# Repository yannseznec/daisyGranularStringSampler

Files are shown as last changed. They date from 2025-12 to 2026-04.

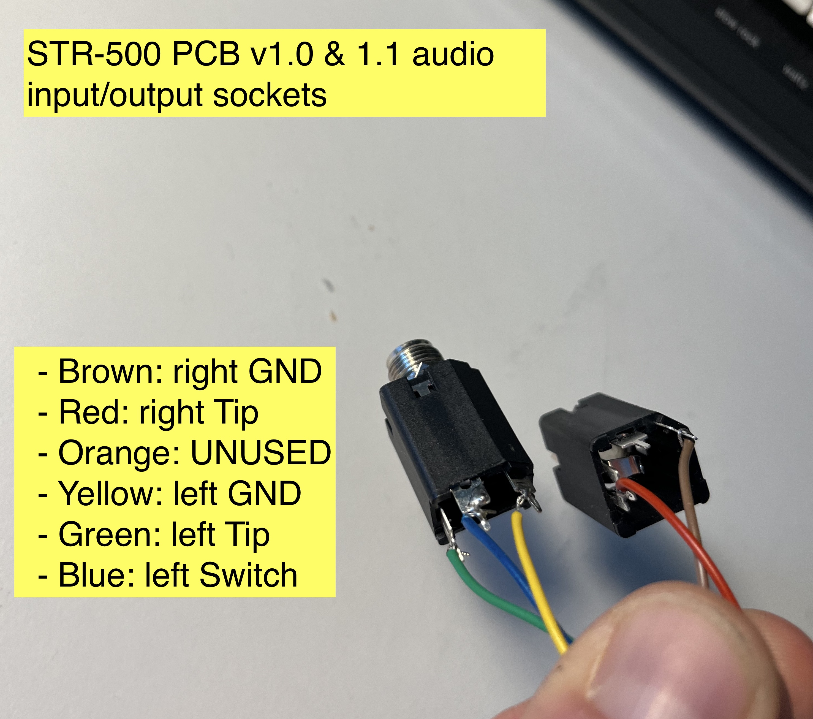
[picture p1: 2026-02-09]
build_notes_etc/picture_audio_sockets.jpg

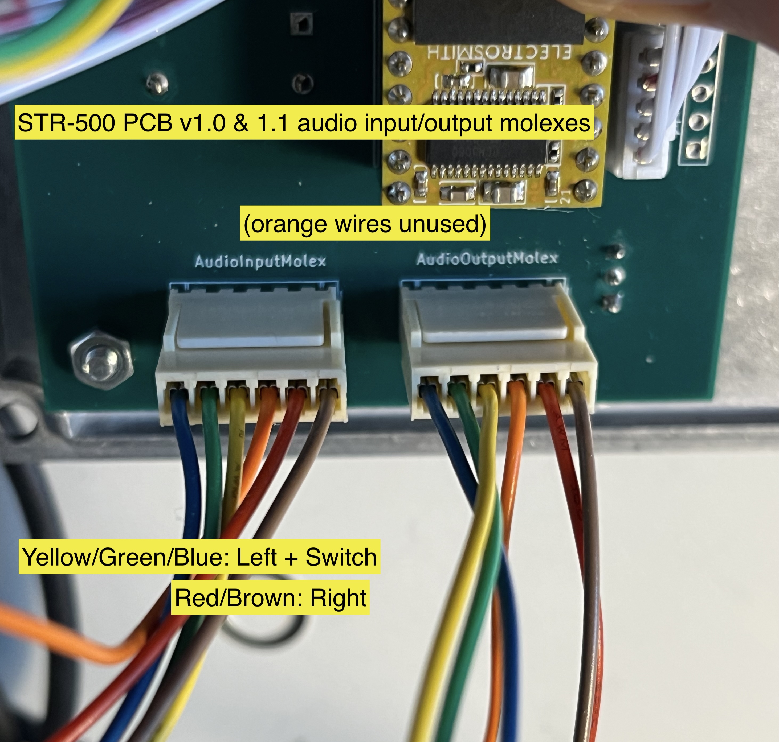
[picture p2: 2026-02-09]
build_notes_etc/picture_audio_molex.jpg

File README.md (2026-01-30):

## STR-500

This is all of the code and build info for the STR-500 gestural granular synthesizer. 

It is a granular synthesizer built for the Daisy Seed which uses a salvaged Gametrak string controller to playback a recorded sample. 

To-do: 
- develop this Readme
- add an actual to-do list to this Readme

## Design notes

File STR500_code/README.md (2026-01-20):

# Granular sampler for Daisy (STR-500)
This is a granular sampling system that runs on a Daisy Seed microcontroller.

Written in Pure Data. The easiest way to get it running on a Seed is to use PlugData for compiling. I use the "Big + SDRAM" SRAM setting in the compiler to allow for the relatively long sampling time. I set the blocksize to 10 for performance and noise reasons. 

This granular patch is essentially the same as the ys.granular system also available here on my github: https://github.com/yannseznec/ys.granular
The main difference is that this version does not use the [clone] object, which is not supported by the Heavy compiler required by the Daisy Seed. There are probably a few other similar changes that I can't remember right now.

This patch is particularly designed for use with a Gametrak string controller, resulting in a gestural sampling machine that I call the STR-500. More details on that coming at some point, you can see videos of it on my instagram if you like: https://www.instagram.com/p/DPdloWzjOOb/

There is a JSON file included for getting the interface elements (buttons, switches, Gametrak) connected to the Seed correctly. At some point I'll make a more detailed guide for how to get that to work. I've also included a KiCAD project for the PCB that I'm working on. This probably isn't the "final" version but it is working. I'll make a list of the components at some point.

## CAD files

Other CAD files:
STR500_v1.1_build/STR500_1-1_drill_drawings/STR500+Drawing+lid.dwg
STR500_v1.1_build/STR500_DXF_from_PCB/Side_gametrak_drill.dxf
STR500_v1.1_build/STR500_1-1_drill_drawings/STR500+Drawing+sockets.dwg
STR500_v1.1_build/STR500_DXF_from_PCB/str500v1.1_holes.dxf
STR500_v1.1_build/STR500_1-1_drill_drawings/STR500+Drawing+gametrak.dwg
STR500_v1.1_build/STR500_DXF_from_PCB/Side_sockets_drill.dxf
STR500_v1.1_build/STR500_1-1_drill_drawings/STR500+Drawing+gametrak.f3z

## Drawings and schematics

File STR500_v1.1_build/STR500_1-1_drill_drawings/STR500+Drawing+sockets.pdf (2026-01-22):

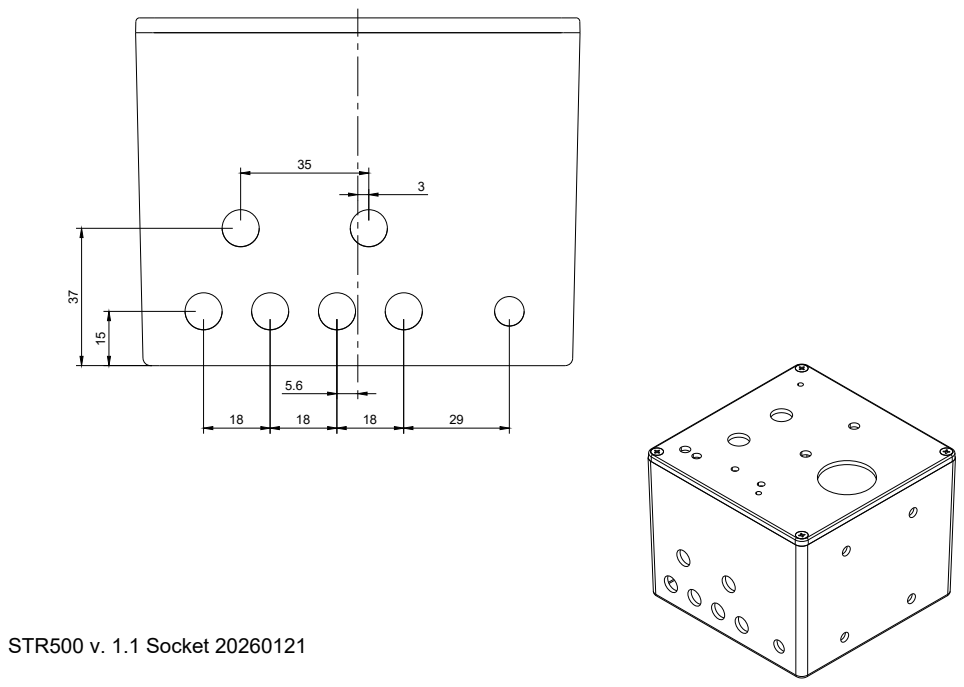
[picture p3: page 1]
STR500 v. 1.1 Socket 20260121

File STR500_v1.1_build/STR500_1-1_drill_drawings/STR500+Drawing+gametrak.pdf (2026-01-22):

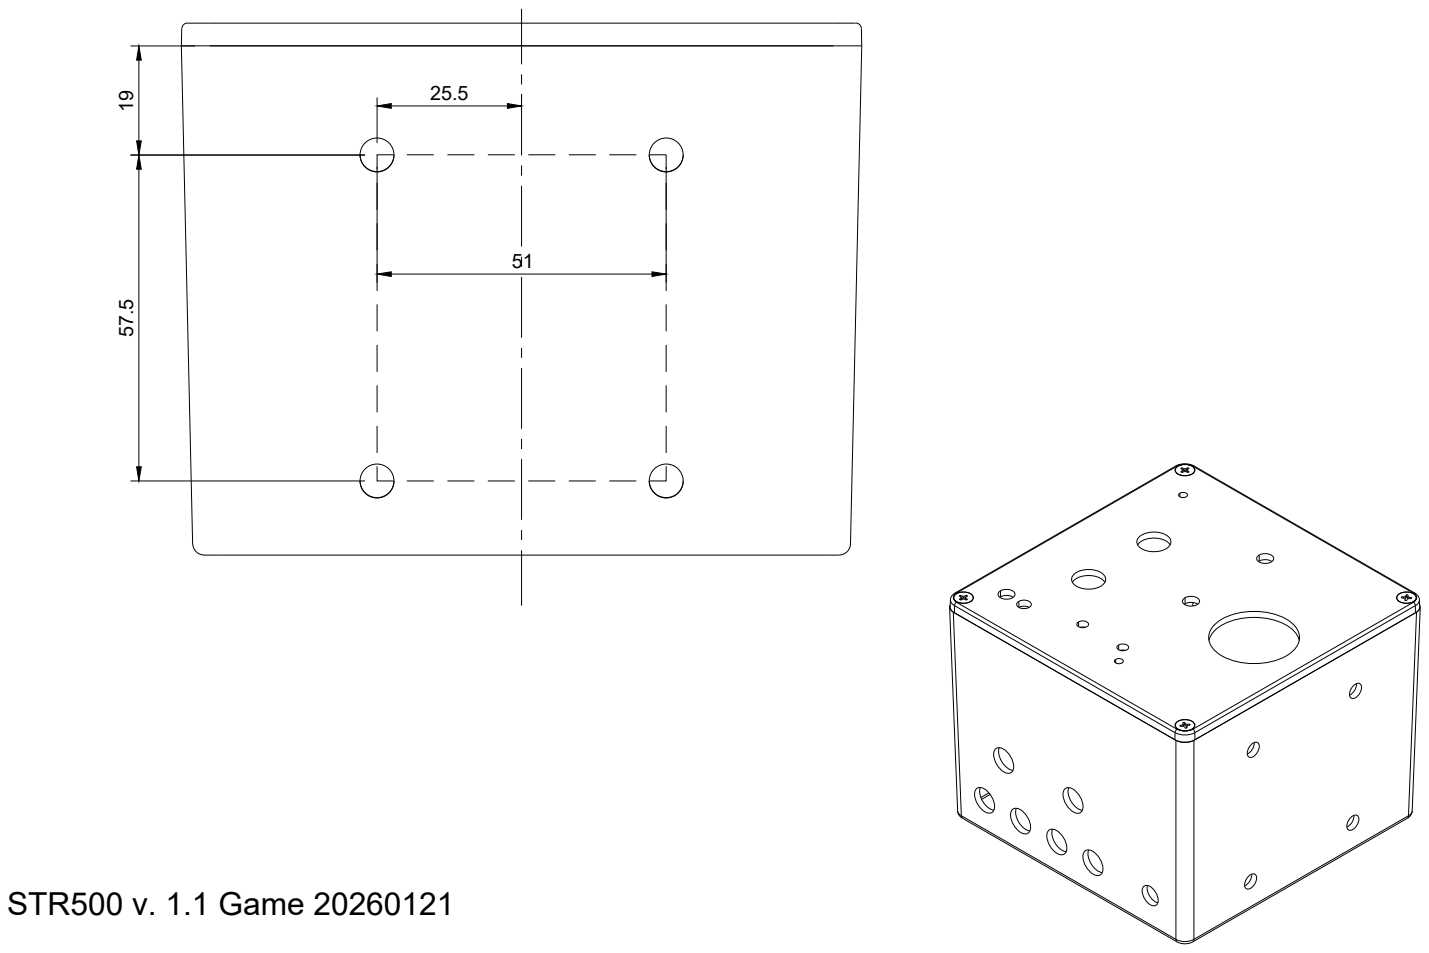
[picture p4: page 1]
STR500 v. 1.1 Game 20260121

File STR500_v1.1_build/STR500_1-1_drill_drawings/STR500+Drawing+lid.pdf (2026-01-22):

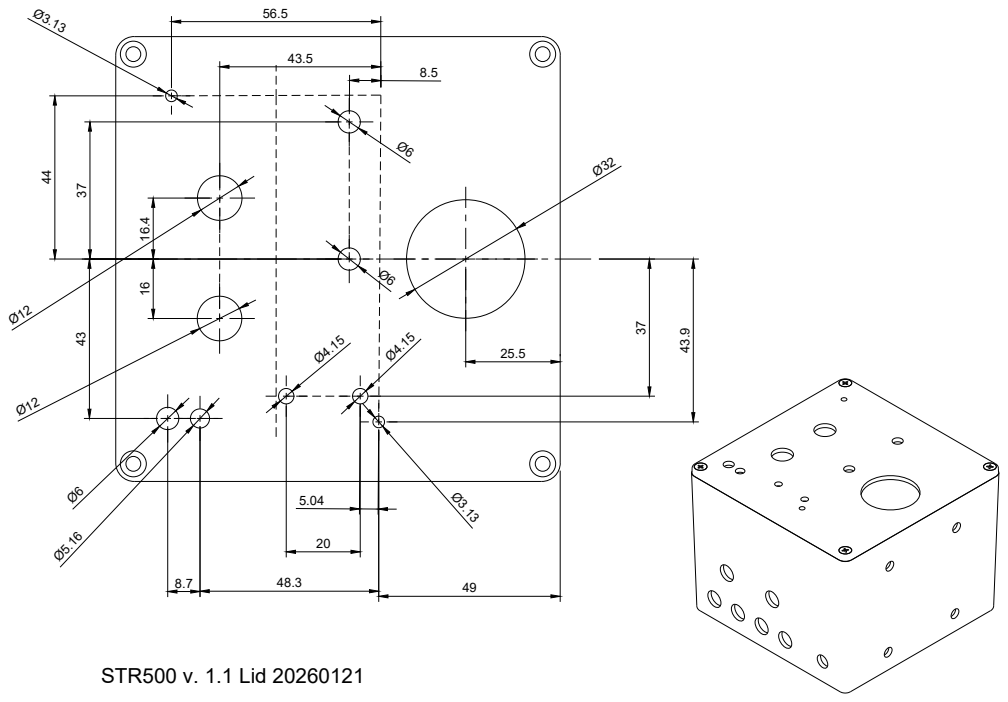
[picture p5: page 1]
STR500 v. 1.1 Lid 20260121

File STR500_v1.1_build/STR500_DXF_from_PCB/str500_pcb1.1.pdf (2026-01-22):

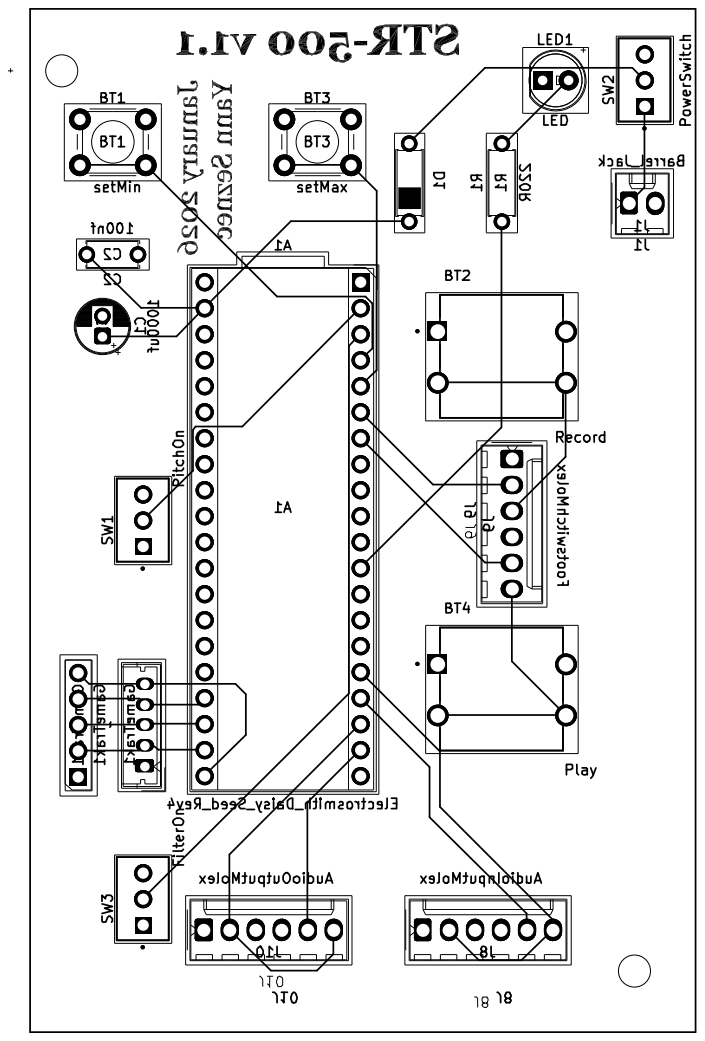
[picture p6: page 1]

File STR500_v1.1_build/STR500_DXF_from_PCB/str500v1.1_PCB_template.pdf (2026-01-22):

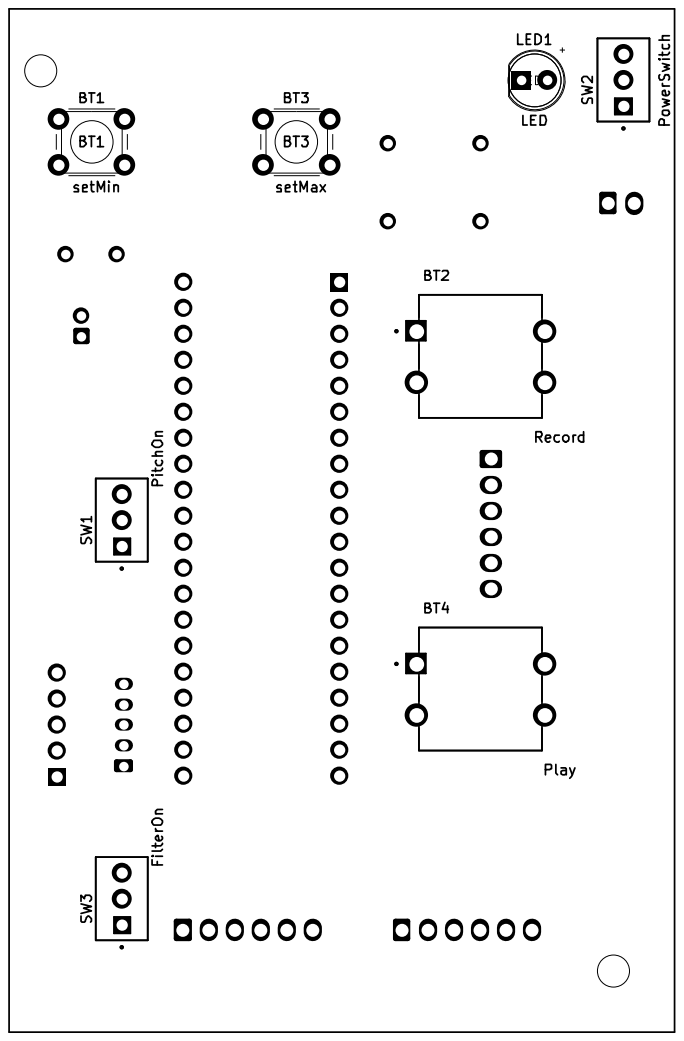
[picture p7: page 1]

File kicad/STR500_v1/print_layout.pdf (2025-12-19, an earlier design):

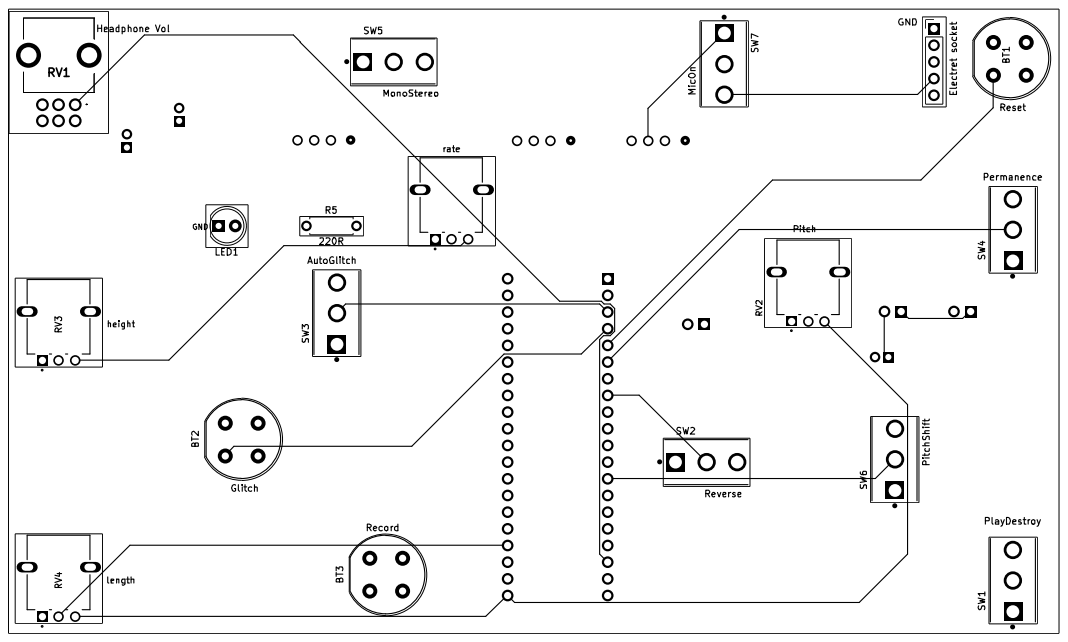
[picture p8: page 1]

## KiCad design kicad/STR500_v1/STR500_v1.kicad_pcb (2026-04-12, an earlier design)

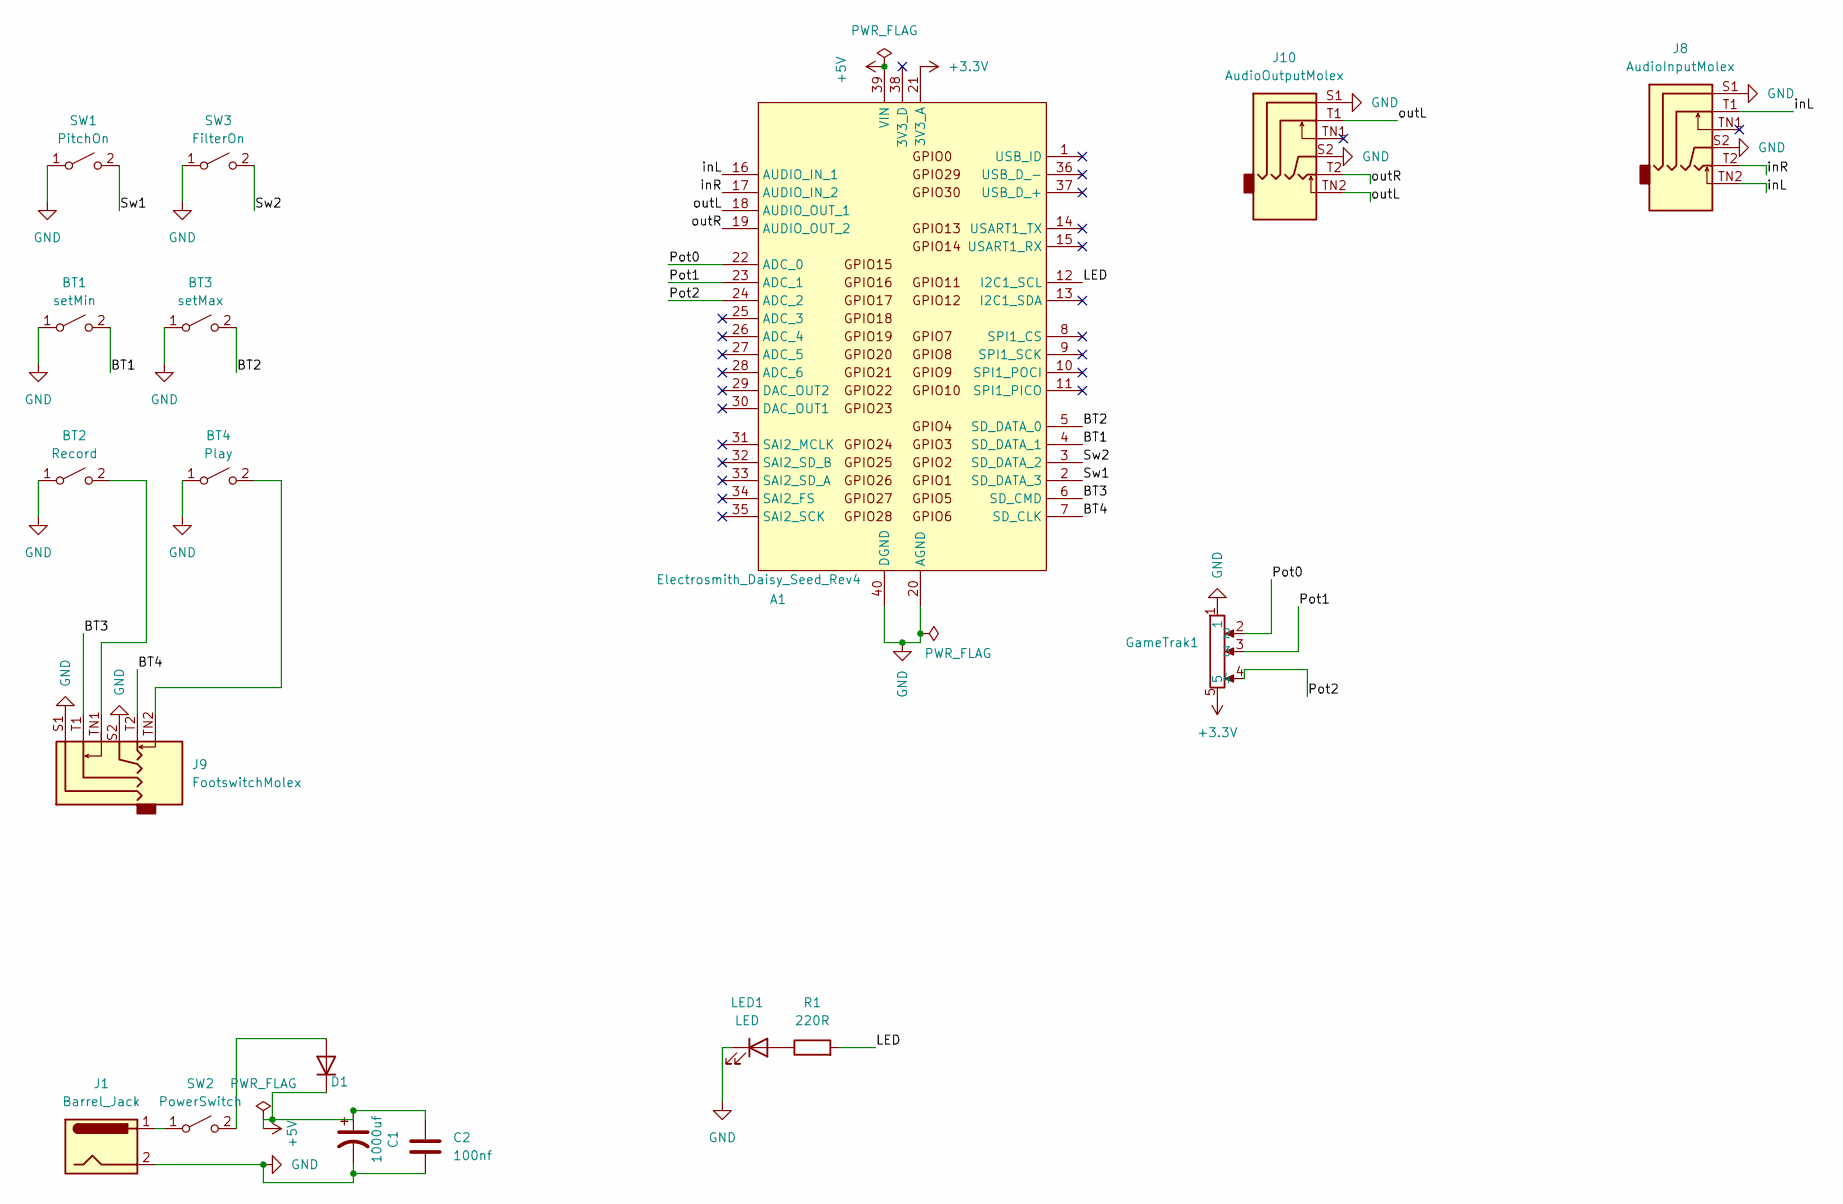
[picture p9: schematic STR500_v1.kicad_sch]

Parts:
A1: Electrosmith_Daisy_Seed_Rev4; Electrosmith_Daisy_Seed
BT1: setMin; SW_PUSH_6mm
BT2: Record; SW_TS13-1212-73-BK-160-D
BT3: setMax; SW_PUSH_6mm
BT4: Play; SW_TS13-1212-73-BK-160-D
C1: 1000uf; CP_Radial_D5.0mm_P2.00mm
C2: 100nf; C_Disc_D5.0mm_W2.5mm_P5.00mm
D1: D; R_Axial_DIN0207_L6.3mm_D2.5mm_P7.62mm_Horizontal
GameTrak1: Molex_Micro-Latch_53253-0570_1x05_P2.00mm_Vertical
J1: Barrel_Jack; Molex_KK-254_AE-6410-02A_1x02_P2.54mm_Vertical
J8: AudioInputMolex; Molex_sixpin_twoJacks
J9: FootswitchMolex; Molex_sixpin_twoJacks
J10: AudioOutputMolex; Molex_sixpin_twoJacks
LED1: LED; LED_D5.0mm
R1: 220R; R_Axial_DIN0207_L6.3mm_D2.5mm_P7.62mm_Horizontal
SW1: PitchOn; submini_toggle
SW2: PowerSwitch; submini_toggle
SW3: FilterOn; submini_toggle

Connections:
+3.3V: A1.21 (3V3_A), GameTrak1.5
+5V: A1.39 (VIN), C1.1, C2.1, D1.1 (K)
/BT1: A1.4 (SD_DATA_1), BT1.2 (B)
/BT2: A1.5 (SD_DATA_0), BT3.2 (B)
/BT3: A1.6 (SD_CMD), J9.T1
/BT4: A1.7 (SD_CLK), J9.T2
/LED: A1.12 (I2C1_SCL), R1.2
/Pot0: A1.22 (ADC_0), GameTrak1.2
/Pot1: A1.23 (ADC_1), GameTrak1.3
/Pot2: A1.24 (ADC_2), GameTrak1.4
/Sw1: A1.2 (SD_DATA_3), SW1.2 (B)
/Sw2: A1.3 (SD_DATA_2), SW3.2 (B)
/inL: A1.16 (AUDIO_IN_1), J8.T1, J8.TN2
/inR: A1.17 (AUDIO_IN_2), J8.T2
/outL: A1.18 (AUDIO_OUT_1), J10.T1, J10.TN2
/outR: A1.19 (AUDIO_OUT_2), J10.T2
GND: A1.20 (AGND), A1.40 (DGND), BT1.1 (A), BT2.1 (A), BT3.1 (A), BT4.1 (A), C1.2, C2.2, GameTrak1.1, J1.2, J8.S1, J8.S2, J9.S1, J9.S2, J10.S1, J10.S2, LED1.1 (K), SW1.1 (A), SW3.1 (A)
unnamed: BT2.2 (B), J9.TN1
unnamed: BT4.2 (B), J9.TN2
unnamed: D1.2 (A), SW2.2 (B)
unnamed: LED1.2 (A), R1.1
unnamed: J1.1, SW2.1 (A)

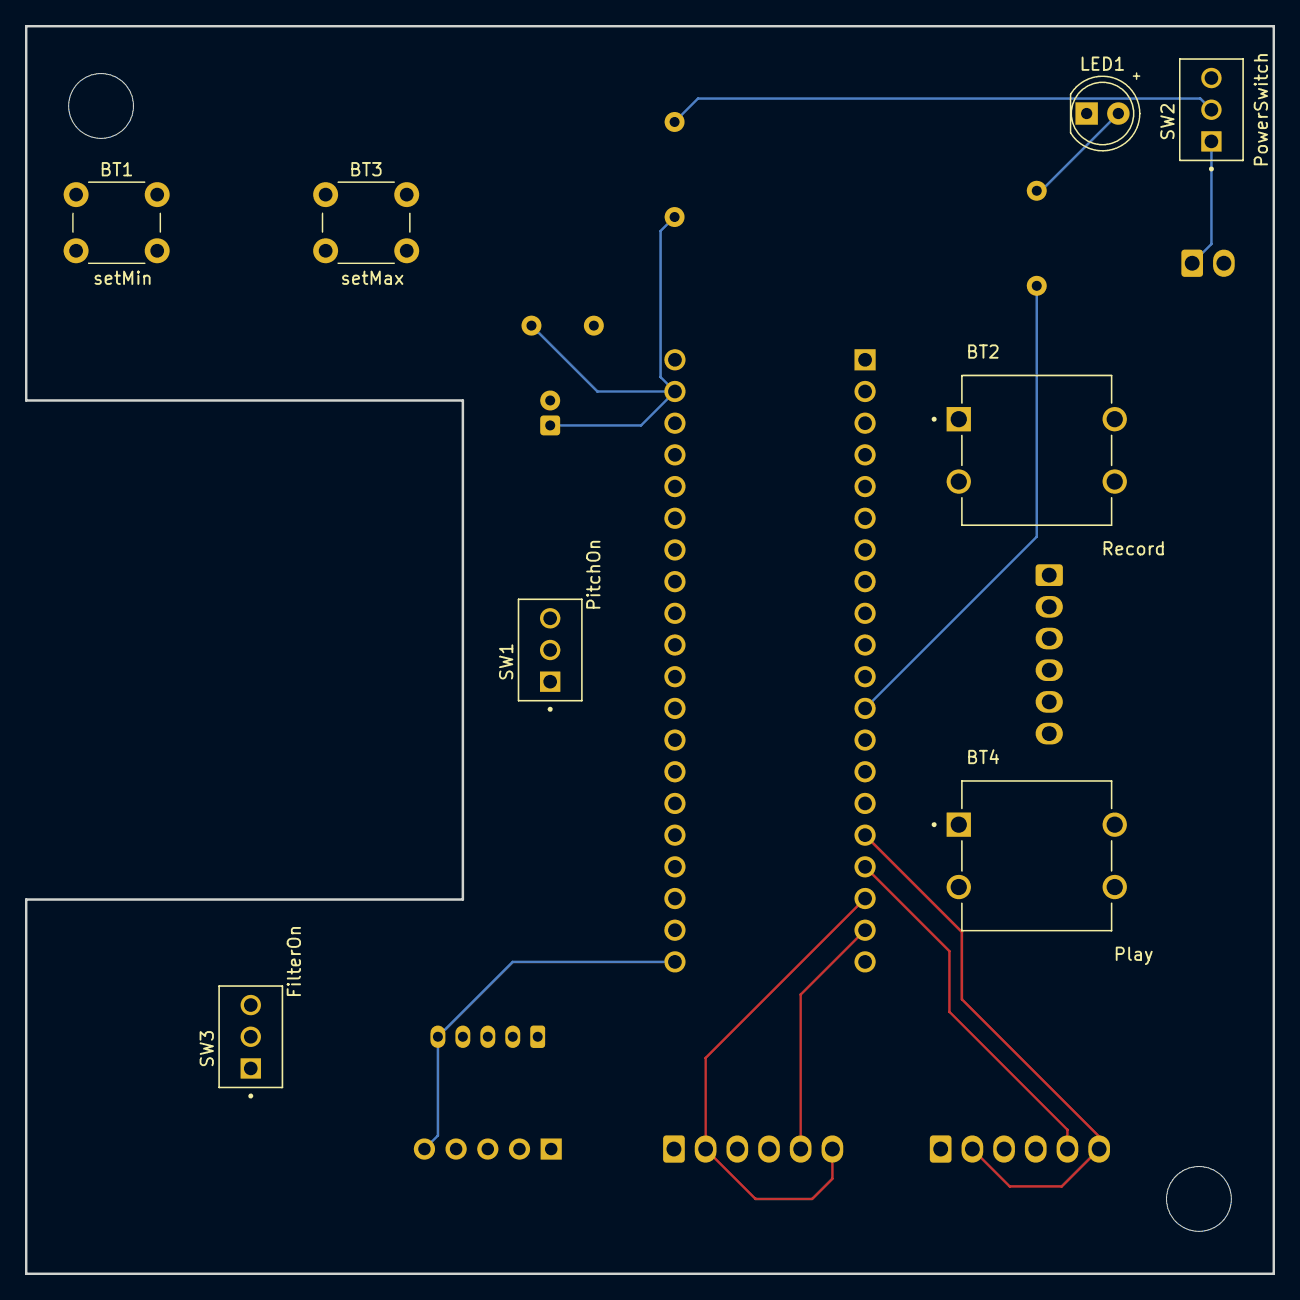
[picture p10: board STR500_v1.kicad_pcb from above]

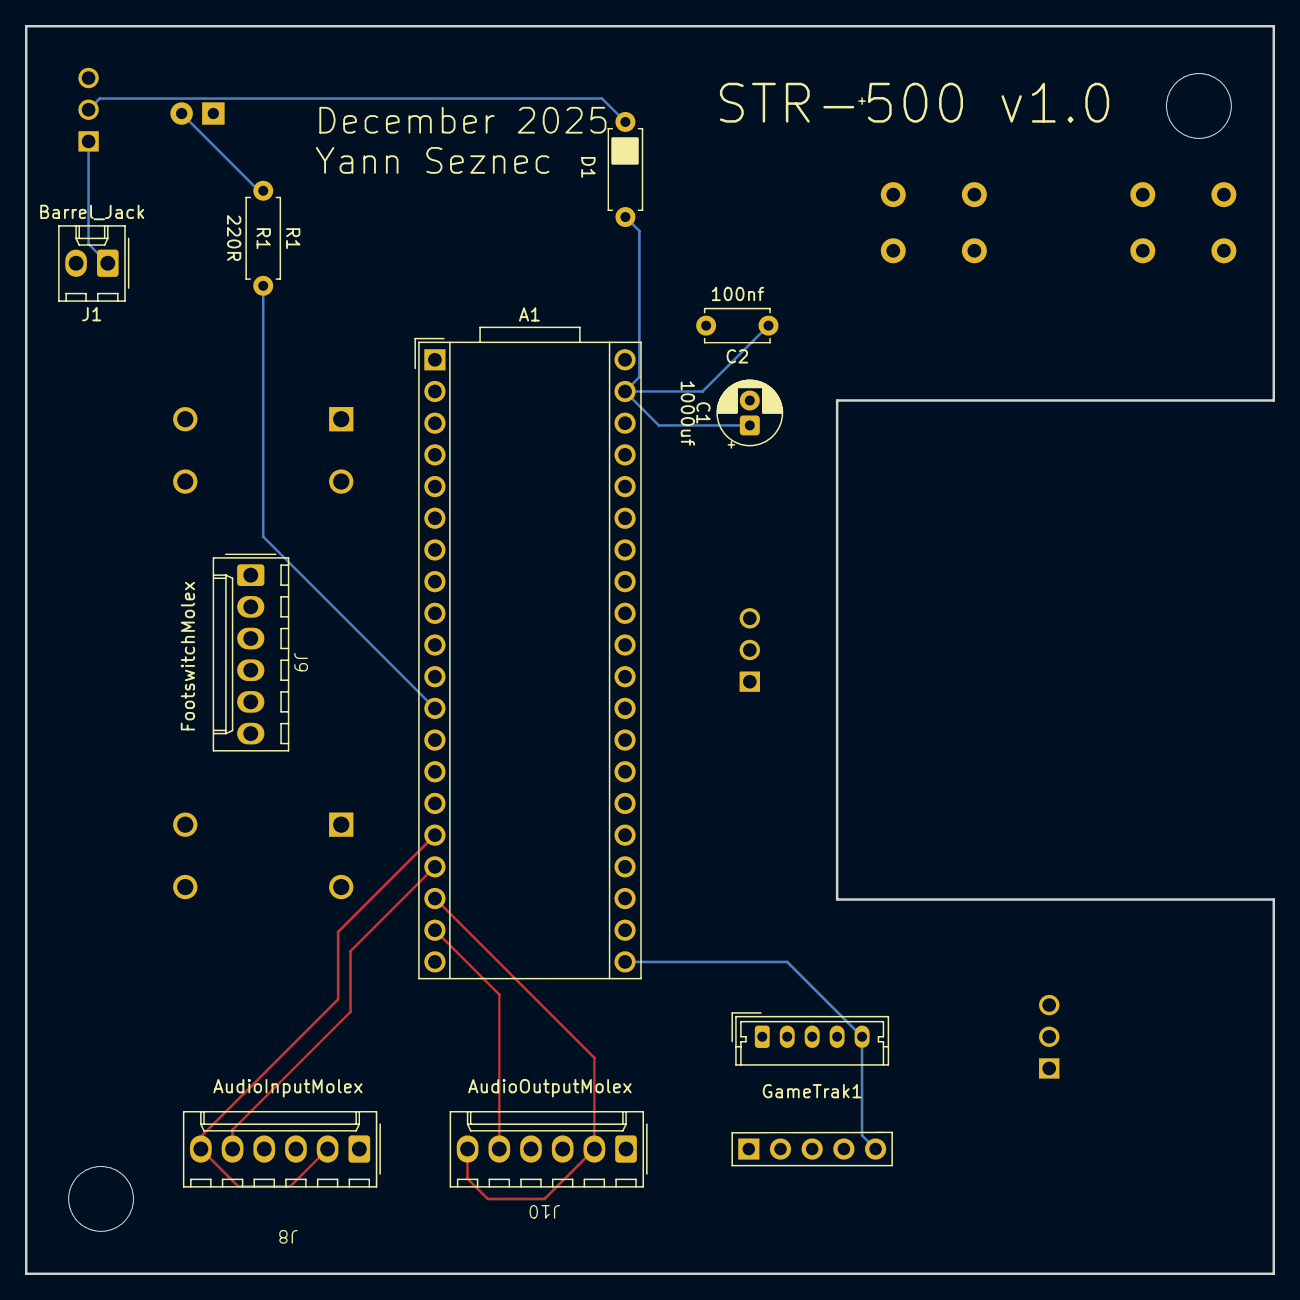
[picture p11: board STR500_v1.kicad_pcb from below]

Board: 4 copper layers, 100.0 x 100.0 mm, 18 parts (10 on the bottom side), 22 nets.

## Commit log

2025-12-19 changes for the PCB version
2025-12-19 added KiCad files
    [STR500_v1-B_Cu.gbl, STR500_v1-B_Mask.gbs, STR500_v1-B_Paste.gbp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]
2026-01-20 new KiCAD, small improvements and cleanup to the Pd patches
    [STR500_v1-B_Cu.gbl, STR500_v1-B_Mask.gbs, STR500_v1-B_Paste.gbp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]
2026-01-22 cleanup and 3D model/drill files
    [STR500+Drawing+gametrak.dwg, STR500+Drawing+gametrak.f3z, STR500+Drawing+lid.dwg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]
2026-04-12 update KiCAD, including first version
    [STR500_v1-B_Cu.gbl, STR500_v1-B_Mask.gbs, STR500_v1-B_Paste.gbp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]
